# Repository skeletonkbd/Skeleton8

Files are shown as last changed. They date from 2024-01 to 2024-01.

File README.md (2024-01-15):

# Skeleton8

 GDPFBt5a0AA_f72

 This is a 4x2 macropad assuming PCBA with stacked acrylic case.

### Firmware here

https://github.com/skeletonkbd/qmk_firmware/tree/Skeleton8/keyboards/skeletonkbd/skeleton8

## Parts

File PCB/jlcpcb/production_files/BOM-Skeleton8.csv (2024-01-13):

Comment | Designator | Footprint | LCSC
1k | R11,R14,R17 | R_0402_1005Metric | C11702
W25Q128JVS | U1 | SOIC-8_5.23x5.23mm_P1.27mm | C131025
100nF | C1,C10,C11,C12,C13,C14,C16,C17,C8,C9 | C_0402_1005Metric | C1525
10uF | C6 | C_0402_1005Metric | C15525
22pF | C2,C3 | C_0402_1005Metric | C1555
RP2040 | U4 | QFN-56-1EP_7x7mm_P0.4mm_EP3.2x3.2mm | C2040
150 | R1,R2,R3,R4,R5,R6,R7,R8 | R_0603_1608Metric | C22808
33 | R9 | R_0603_1608Metric | C23140
27 | R15,R16 | R_0603_1608Metric | C25190
10k | R10 | R_0603_1608Metric | C25804
5k1 | R12,R13 | R_0402_1005Metric | C25905
USBLC6-2SC6 | U2 | SOT-23-6 | C2827654
SI2302 | Q1 | SOT-23 | C2891732
1uF | C15,C4,C5,C7 | C_0402_1005Metric | C52923
XC6206PxxxMR | U3 | SOT-23-3 | C5446
LTW-C230DS | LED1,LED2,LED3,LED4,LED5,LED6,LED7,LED8 | LTW-C230DS | C575513
500mA | F1 | Fuse_1206_3216Metric | C70076
SW_Push | TS1,TS2 | TS-1088 | C720477
12MHz | Y1 | Crystal_SMD_3225-4Pin_3.2x2.5mm | C9002
TYPE-C-31-M-12 | J1 | USB_C_Receptacle_Hroparts_TYPE-C-31-M-12

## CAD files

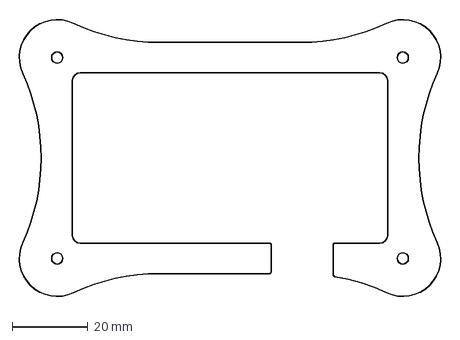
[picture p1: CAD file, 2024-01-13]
Case/dxf/lower_middle.dxf
112.6 x 74.5 mm

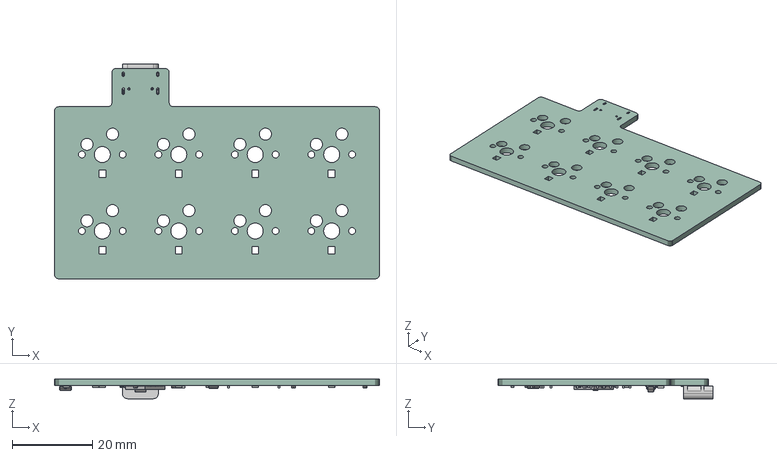
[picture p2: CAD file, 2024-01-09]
PCB/Skeleton8.step
81.0 x 53.5 x 4.86 mm
_autosave-Skeleton8 PCB

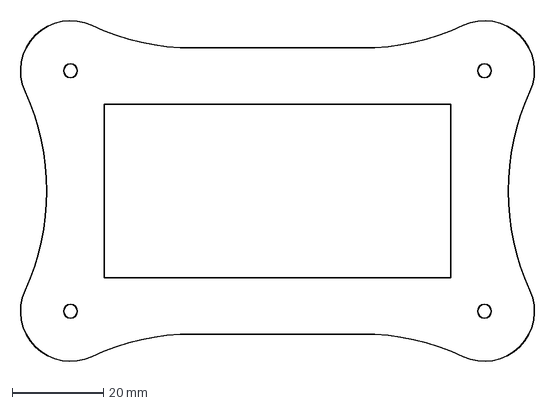
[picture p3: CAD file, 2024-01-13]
Case/dxf/top.dxf
114.8 x 76.7 mm

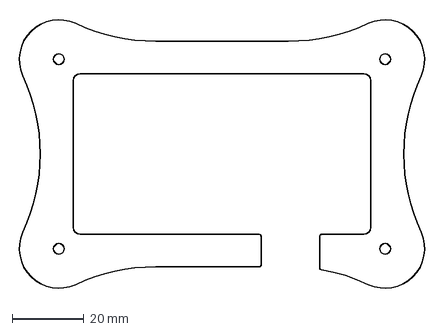
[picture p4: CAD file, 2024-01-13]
Case/dxf/upper_middle.dxf
114.8 x 76.7 mm

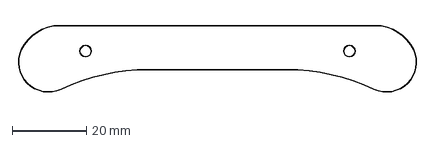
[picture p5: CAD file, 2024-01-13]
Case/dxf/feet.dxf
108.3 x 18.5 mm

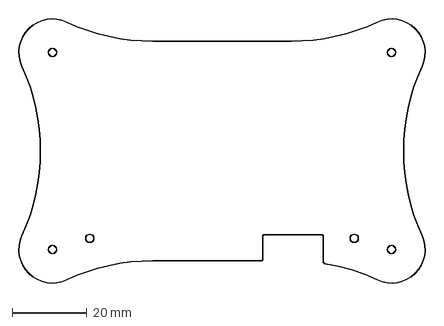
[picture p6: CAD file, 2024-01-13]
Case/dxf/bottom.dxf
110.5 x 72.4 mm

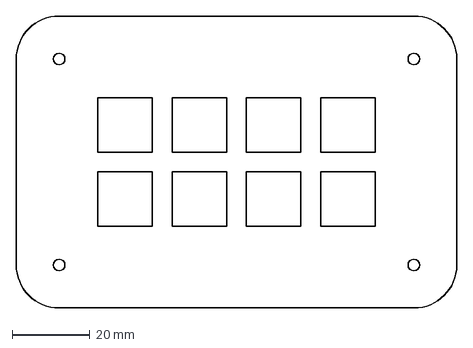
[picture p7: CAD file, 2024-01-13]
Case/dxf/switch.dxf
113.0 x 74.9 mm

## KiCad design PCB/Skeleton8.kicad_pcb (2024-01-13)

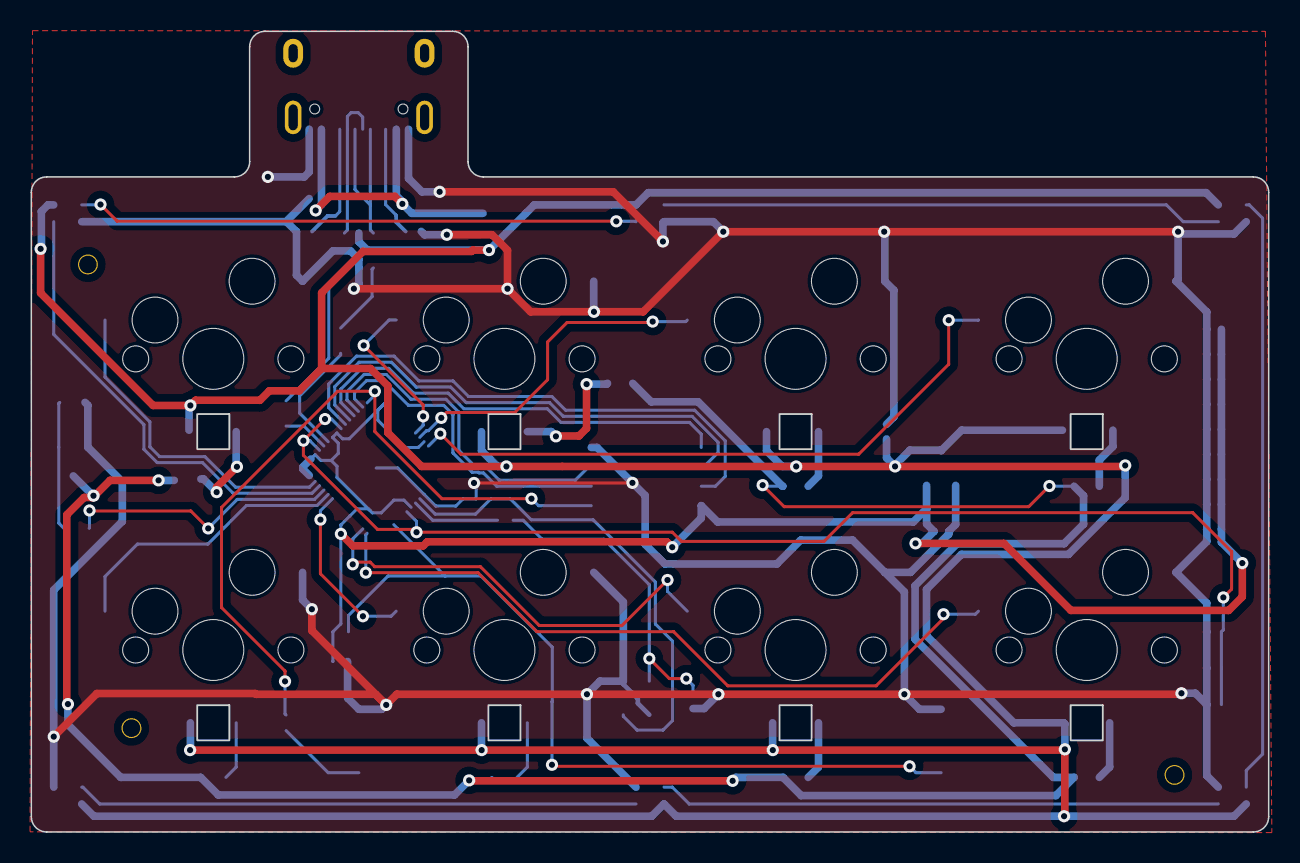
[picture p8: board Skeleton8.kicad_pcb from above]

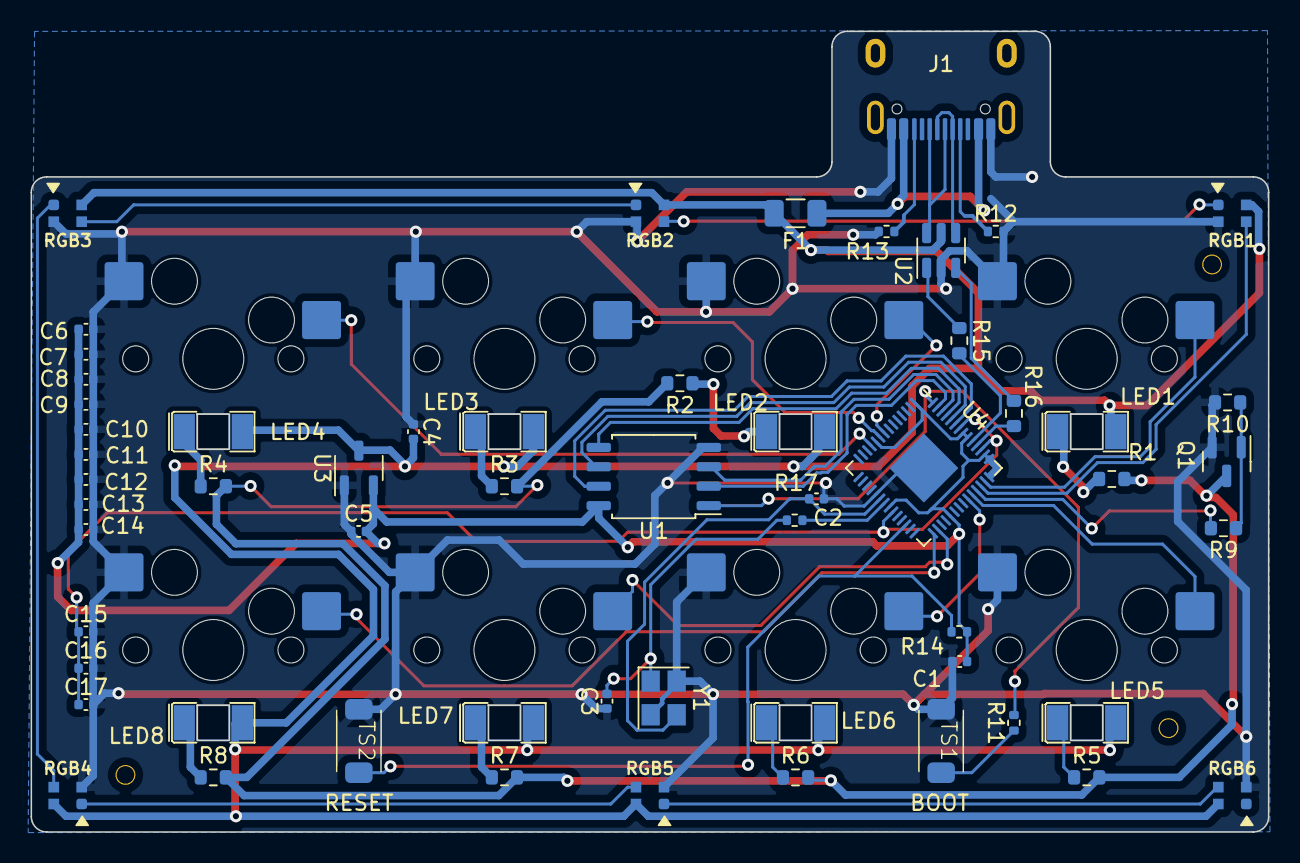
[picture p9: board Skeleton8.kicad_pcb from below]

Board: 2 copper layers, 81.0 x 52.4 mm, 69 parts (66 on the bottom side), 49 nets.

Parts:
C1, C8, C9, C10, C11, C12, C13, C14, C16, C17: 100nF; C_0402_1005Metric
C2, C3: 22pF; C_0402_1005Metric
C4, C5, C7, C15: 1uF; C_0402_1005Metric
C6: 10uF; C_0402_1005Metric
F1: 500mA; Fuse_1206_3216Metric
H1, H2, H3: Hole; ToolingHole
J1: TYPE-C-31-M-12; USB_C_Receptacle_Hroparts_TYPE-C-31-M-12
LED1, LED2, LED3, LED4, LED5, LED6, LED7, LED8: LTW-C230DS
Q1: SI2302; SOT-23
R1, R2, R3, R4, R5, R6, R7, R8: 150; R_0603_1608Metric
R9: 33; R_0603_1608Metric
R10: 10k; R_0603_1608Metric
R11, R14, R17: 1k; R_0402_1005Metric
R12, R13: 5k1; R_0402_1005Metric
R15, R16: 27; R_0603_1608Metric
RGB1, RGB2, RGB3, RGB4, RGB5, RGB6: WS2812B-2020; LED_WS2812_2020
SW1, SW2, SW3, SW4, SW5, SW6, SW7, SW8: SW_Push; MX-Hotswap-1U
TS1, TS2: SW_Push; TS-1088
U1: W25Q128JVS; SOIC-8_5.23x5.23mm_P1.27mm
U2: USBLC6-2SC6; SOT-23-6
U3: XC6206PxxxMR; SOT-23-3
U4: RP2040; QFN-56-1EP_7x7mm_P0.4mm_EP3.2x3.2mm
Y1: 12MHz; Crystal_SMD_3225-4Pin_3.2x2.5mm

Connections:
+1V1: C15.1, C16.1, C17.1, U4.23 (DVDD), U4.45 (VREG_VOUT), U4.50 (DVDD)
+3V3: C1.1, C5.2, C6.1, C7.1, C8.1, C9.1, C10.1, C11.1, C12.1, C13.1, C14.1, R14.1, U1.8 (VCC), U3.2 (VO), U4.1 (IOVDD), U4.10 (IOVDD), U4.22 (IOVDD), U4.33 (IOVDD), U4.42 (IOVDD), U4.43 (ADC_AVDD), U4.44 (VREG_IN), U4.48 (USB_VDD), U4.49 (IOVDD)
+5V: C4.2, F1.2, LED1.2 (A), LED2.2 (A), LED3.2 (A), LED4.2 (A), LED5.2 (A), LED6.2 (A), LED7.2 (A), LED8.2 (A), RGB1.4 (VDD), RGB2.4 (VDD), RGB3.4 (VDD), RGB4.4 (VDD), RGB5.4 (VDD), RGB6.4 (VDD), U2.5 (VBUS), U3.3 (VI)
/CC1: J1.A5 (CC1), R12.1
/CC2: J1.B5 (CC2), R13.1
/D_+: R15.2, U4.47 (USB_DP)
/D_-: R16.2, U4.46 (USB_DM)
/XTAL_O: C3.2, R17.1, Y1.1
/~USB_BOOT: R11.1, TS1.2
CS: R11.2, U1.1 (~CS), U4.56 (QSPI_SS)
D_N: R16.1, U2.3 (I/O2)
D_P: R15.1, U2.1 (I/O1)
D_USB_N: J1.A7 (D-), J1.B7 (D-), U2.4 (I/O2)
D_USB_P: J1.A6 (D+), J1.B6 (D+), U2.6 (I/O1)
GND: C1.2, C2.1, C3.1, C4.1, C5.1, C6.2, C7.2, C8.2, C9.2, C10.2, C11.2, C12.2, C13.2, C14.2, C15.2, C16.2, C17.2, J1.A1 (GND), J1.B1 (GND), Q1.2 (S), R10.2, R12.2, R13.2, RGB1.2 (VSS), RGB2.2 (VSS), RGB3.2 (VSS), RGB4.2 (VSS), RGB5.2 (VSS), RGB6.2 (VSS), SW1.2, SW2.2, SW3.2, SW4.2, SW5.2, SW6.2, SW7.2, SW8.2, TS1.1, TS2.1, U1.4 (GND), U2.2 (GND), U3.1 (GND), U4.19 (TESTEN), U4.57 (GND), Y1.2, Y1.4
unnamed: LED1.1 (K), R1.1
unnamed: LED2.1 (K), R2.1
unnamed: LED3.1 (K), R3.1
unnamed: LED4.1 (K), R4.1
unnamed: LED5.1 (K), R5.1
unnamed: LED6.1 (K), R6.1
unnamed: LED7.1 (K), R7.1
unnamed: LED8.1 (K), R8.1
unnamed: Q1.3 (D), R1.2, R2.2, R3.2, R4.2, R5.2, R6.2, R7.2, R8.2
unnamed: Q1.1 (G), R9.1, R10.1
unnamed: RGB1.1 (DOUT), RGB2.3 (DIN)
unnamed: RGB2.1 (DOUT), RGB3.3 (DIN)
unnamed: RGB3.1 (DOUT), RGB4.3 (DIN)
unnamed: RGB4.1 (DOUT), RGB5.3 (DIN)
unnamed: RGB5.1 (DOUT), RGB6.3 (DIN)
QSPI_CLK: U1.6 (CLK), U4.52 (QSPI_SCLK)
SD0: U1.5 (DI(IO0)), U4.53 (QSPI_SD0)
SD1: U1.2 (DO(IO1)), U4.55 (QSPI_SD1)
SD2: U1.3 (IO2), U4.54 (QSPI_SD2)
SD3: U1.7 (IO3), U4.51 (QSPI_SD3)
VBUS: F1.1, J1.A4 (VBUS), J1.B4 (VBUS)
XTAL_IN: C2.2, U4.20 (XIN), Y1.3
XTAL_OUT: R17.2, U4.21 (XOUT)
backlight: R9.2, U4.39 (GPIO27_ADC1)
key1: SW1.1, U4.41 (GPIO29_ADC3)
key2: SW2.1, U4.8 (GPIO6)
key3: SW3.1, U4.9 (GPIO7)
key4: SW4.1, U4.11 (GPIO8)
key5: SW5.1, U4.38 (GPIO26_ADC0)
key6: SW6.1, U4.37 (GPIO25)
key7: SW7.1, U4.30 (GPIO19)
key8: SW8.1, U4.29 (GPIO18)
underglow: RGB1.3 (DIN), U4.40 (GPIO28_ADC2)
~RESET: R14.2, TS2.2, U4.26 (RUN)
